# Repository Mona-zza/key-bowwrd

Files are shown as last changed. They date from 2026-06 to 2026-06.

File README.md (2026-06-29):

# ChapBoard

As my final exams are over and I've nothing to do untill first week of july so I utlized that time in upgrading my skill, I'm on my PC all the time and in thses time I've made this keyboard.

My this keyboard is equiped with 89 keys, 1 rotary encoder switch and 0.91" OLED display. In this I've used Raspberry Pi Pico 2W. I used this microcontroller because I guess it will be good because it has just enough GPIO pins for the key matrix + OLED and rotary encoder, and the 2W version of the Pico has wireless through the help of bluetooth if I decide to add that functionality in the future. For the case It has 2 separate printed pieces. The base, where the PCB sits, and the top cover, which protects the PCB. and I'll modify the CAD when I get more exact mesurments when the PCB will arrive!!

# Image











# Cart

cart1



## Bill of Materials (BOM)

| Item | Purpose | Qty | Total Price (USD) | Purchase Link | Distributor |
|---|---|----:|---:|---|---|
| PCB | PCB | 1 | $22.43 | N/A | JLCPCB |
| Raspberry Pi Pico 2W | Microcontroller | 1 | $14.82 | https://www.amazon.in/Raspberry-Dual-Core-Microcontroller-Cortex-M33-Bluetooth | Amazon |
| 0.91" OLED Display | Display | 1 | $4.11 | https://www.amazon.in/gp/product/B084H9HLCS | Amazon |
| 1N4148 Diodes | Diodes | 100 | $1.56 | https://www.amazon.in/gp/product/B0DRMGYSXB | Amazon |
| Rotary Encoder | Rotary Encoder | 1 | $1.82 | https://www.amazon.in/gp/product/B0888RWNM1 | Amazon |
| Cherry MX Switches | Switches | 89 | $5.28 | https://www.amazon.in/gp/product/B0G39H2G4H | Amazon |
| Keycaps | Keycaps | 89 | $10.56 | https://www.amazon.in/gp/product/B0GFNPXVJL | Amazon |
| Keycap Stabilizers Pack | Stabilizers | 1 | $9.18 | https://www.amazon.in/gp/product/B0GVKSLP46 | Amazon |
| Adafruit MCP23017 I²C GPIO Expander Breakout | GPIO Expander | 1 | $33.44 | https://www.amazon.in/gp/product/B0BPN3BD1Q | Amazon |
| M3×5×4 Heatset Inserts | Heatset Inserts | 1 | $2.07 | https://www.amazon.in/gp/product/B0CX1BS7DJ | Amazon |

### Total Cost

**≈ $105.27 USD**

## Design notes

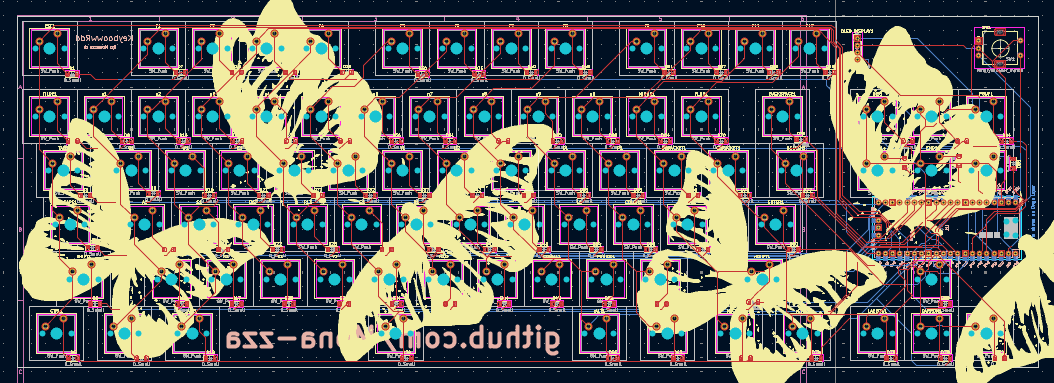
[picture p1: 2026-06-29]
Images/Screenshot2.png

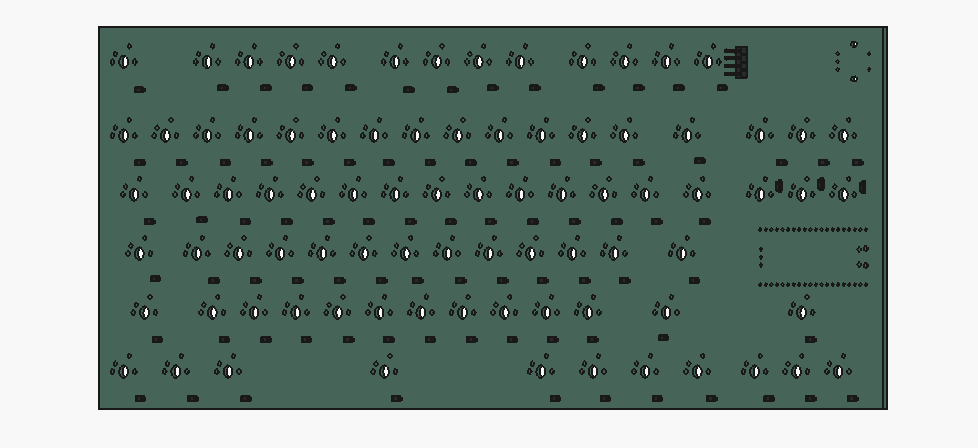
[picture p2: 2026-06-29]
Images/Screenshot7.png

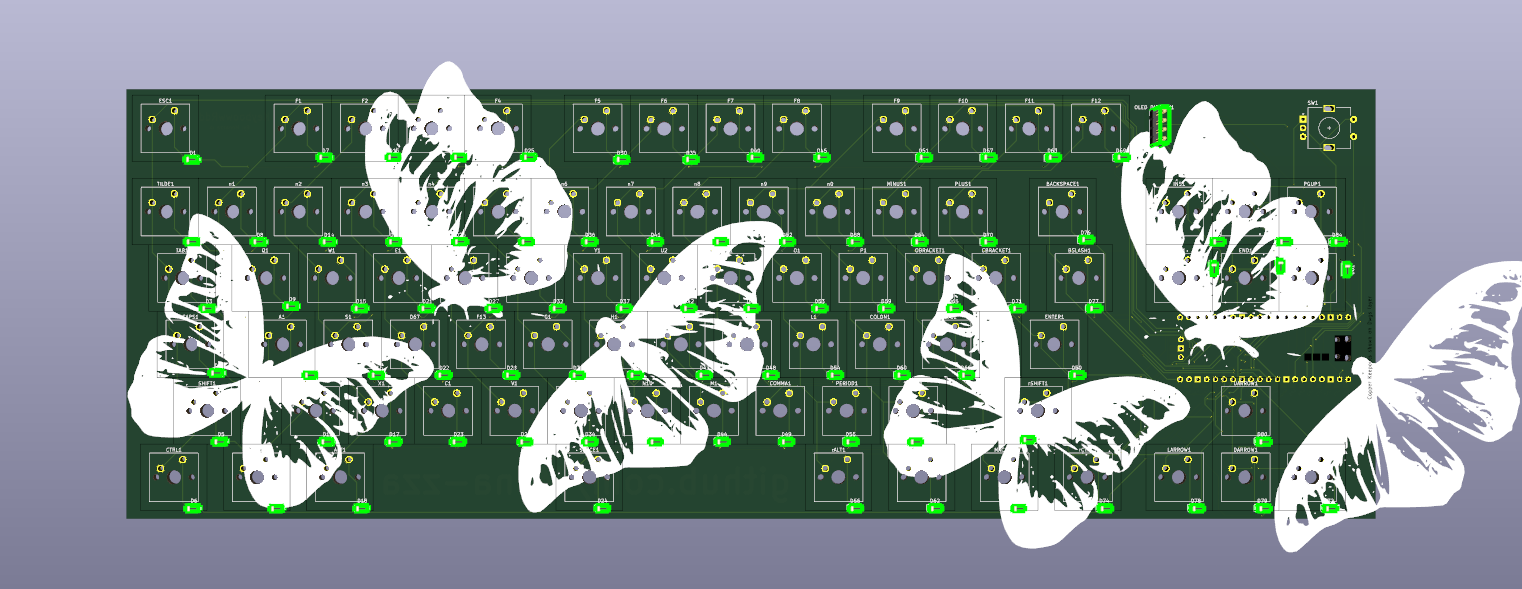
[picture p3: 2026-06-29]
Images/Screenshot3.png

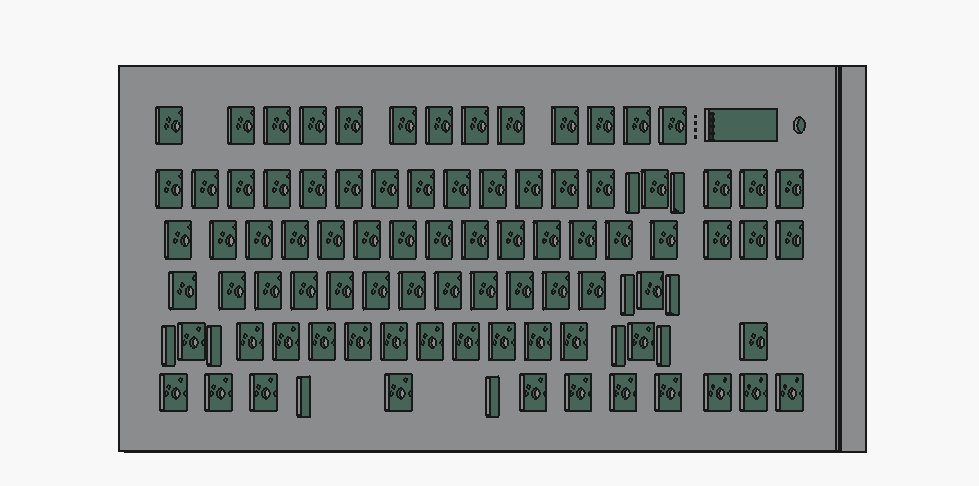
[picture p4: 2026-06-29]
Images/Screenshot6.png

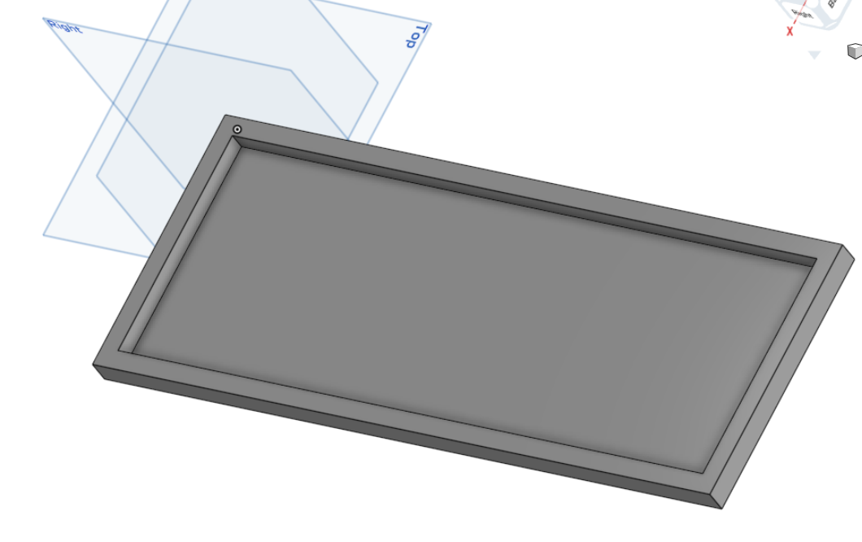
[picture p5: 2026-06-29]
Images/Screenshot4.png

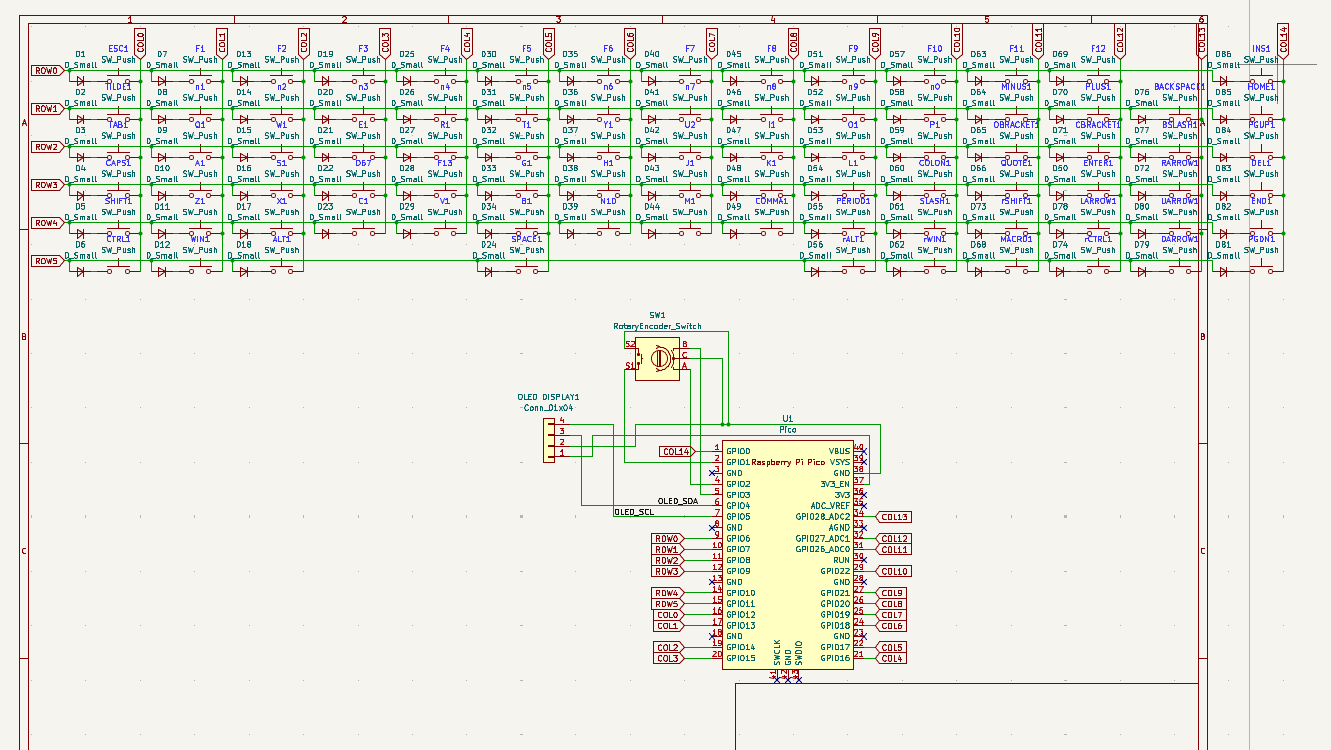
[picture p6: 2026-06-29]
Images/Screenshot1.png

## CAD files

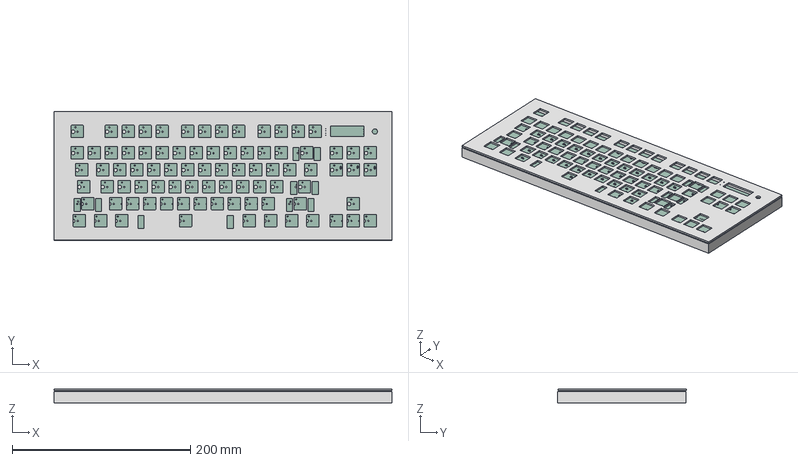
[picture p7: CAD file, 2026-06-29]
CAD/assembly.step
379.1 x 144.4 x 16.1 mm
D_SOD-123 x 84
PinHeader_1x04_P2.54mm_Vertical
keyboard_PCB

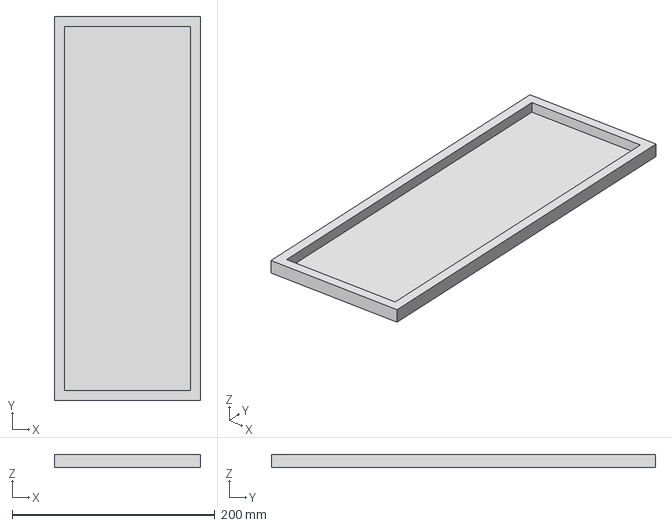
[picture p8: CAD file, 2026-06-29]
CAD/Keyboard-bottom.step
144.2 x 379.1 x 13.0 mm

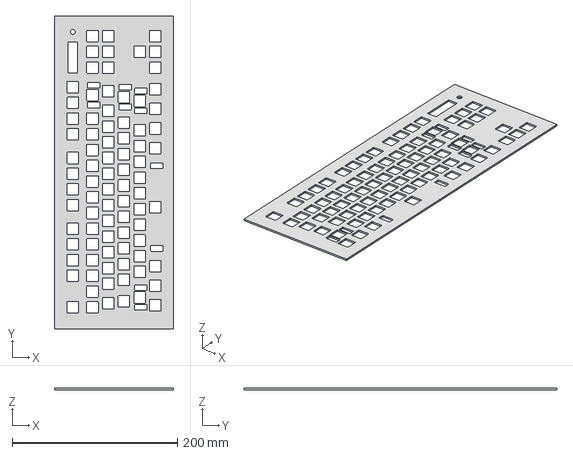
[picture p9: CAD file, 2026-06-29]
CAD/Keyboard-top.step
144.2 x 379.1 x 2.00 mm

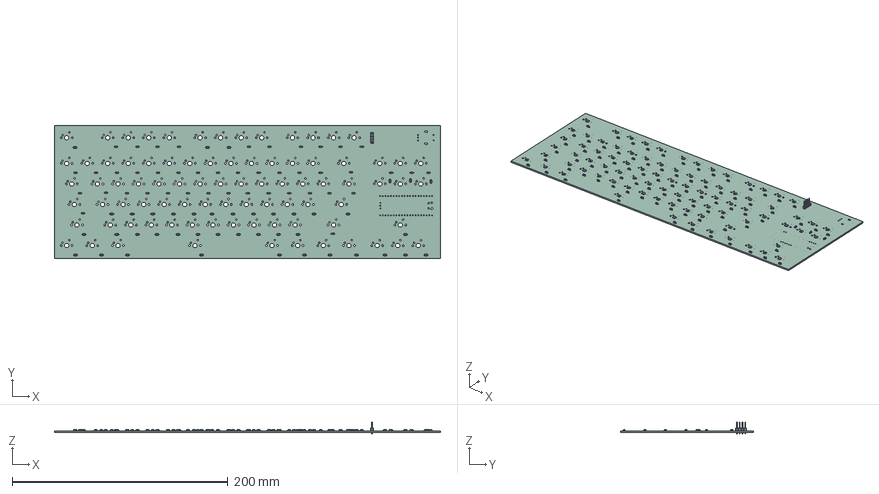
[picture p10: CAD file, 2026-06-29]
CAD/pcb.step
358.1 x 123.2 x 11.5 mm
D_SOD-123 x 84
PinHeader_1x04_P2.54mm_Vertical
keyboard_PCB

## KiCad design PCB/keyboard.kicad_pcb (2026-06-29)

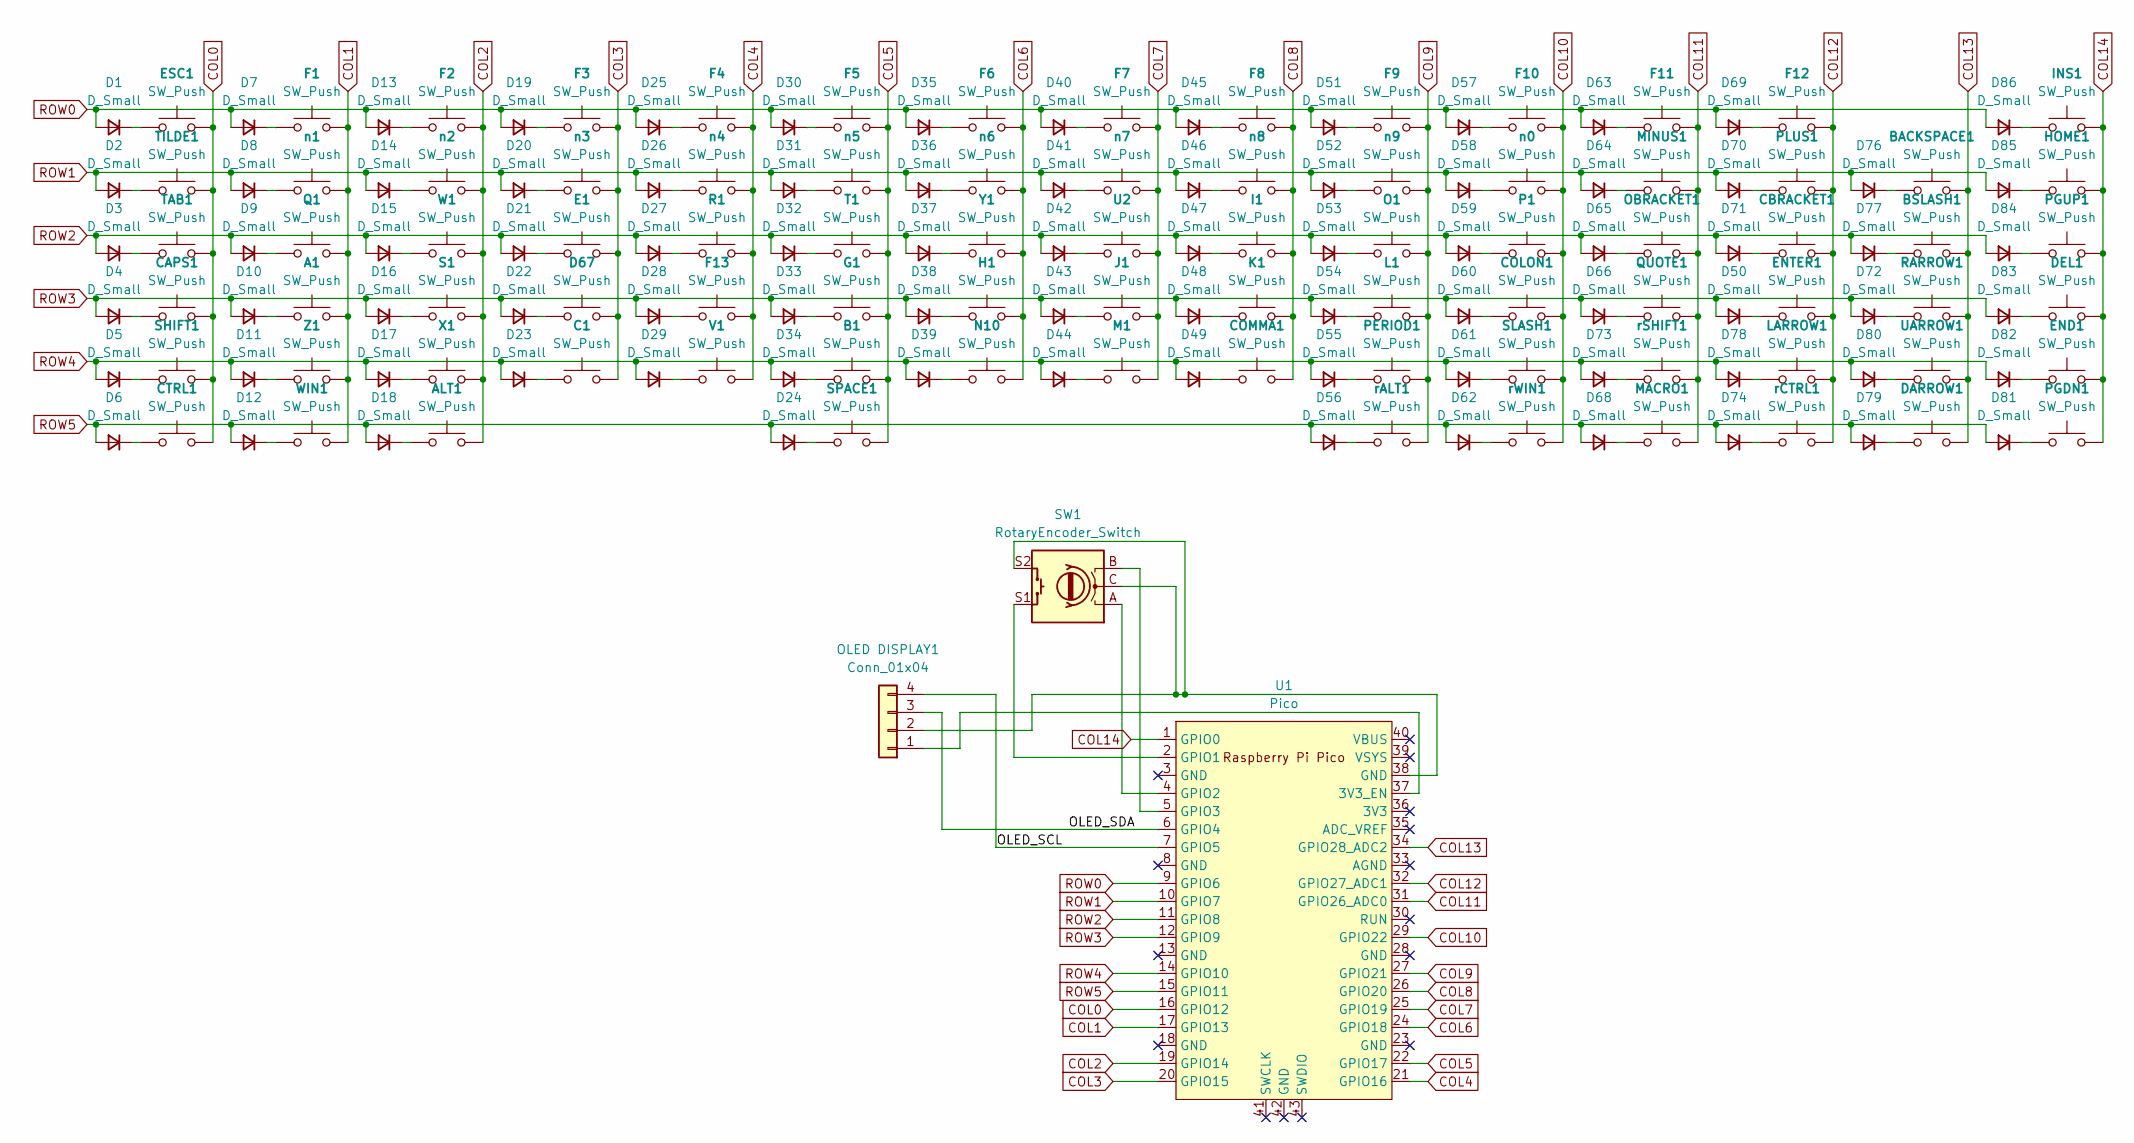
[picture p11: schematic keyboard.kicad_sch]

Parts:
A1: SW_Push; SW_Cherry_MX_1.00u_PCB
ALT1: SW_Push; SW_Cherry_MX_1.00u_PCB
B1: SW_Push; SW_Cherry_MX_1.00u_PCB
BACKSPACE1: SW_Push; SW_Cherry_MX_1.00u_PCB
BSLASH1: SW_Push; SW_Cherry_MX_1.00u_PCB
C1: SW_Push; SW_Cherry_MX_1.00u_PCB
CAPS1: SW_Push; SW_Cherry_MX_1.00u_PCB
CBRACKET1: SW_Push; SW_Cherry_MX_1.00u_PCB
COLON1: SW_Push; SW_Cherry_MX_1.00u_PCB
COMMA1: SW_Push; SW_Cherry_MX_1.00u_PCB
CTRL1: SW_Push; SW_Cherry_MX_1.00u_PCB
D1, D2, D3, D4, D5, D6, D7, D8, D9, D10, D11, D12, D13, D14, D15, D16, D17, D18, D19, D20, D21, D22, D23, D24, D25, D26, D27, D28, D29, D30, D31, D32, D33, D34, D35, D36, D37, D38, D39, D40, D41, D42, D43, D44, D45, D46, D47, D48, D49, D50, D51, D52, D53, D54, D55, D56, D57, D58, D59, D60, D61, D62, D63, D64, D65, D66, D68, D69, D70, D71, D72, D73, D74, D76, D77, D78, D79, D80, D81, D82, D83, D84, D85, D86: D_Small; D_SOD-123
D67: SW_Push; SW_Cherry_MX_1.00u_PCB
DARROW1: SW_Push; SW_Cherry_MX_1.00u_PCB
DEL1: SW_Push; SW_Cherry_MX_1.00u_PCB
E1: SW_Push; SW_Cherry_MX_1.00u_PCB
END1: SW_Push; SW_Cherry_MX_1.00u_PCB
ENTER1: SW_Push; SW_Cherry_MX_1.00u_PCB
ESC1: SW_Push; SW_Cherry_MX_1.00u_PCB
F1, F2, F3, F4, F5, F6, F7, F8, F9, F10, F11, F12, F13: SW_Push; SW_Cherry_MX_1.00u_PCB
G1: SW_Push; SW_Cherry_MX_1.00u_PCB
H1: SW_Push; SW_Cherry_MX_1.00u_PCB
HOME1: SW_Push; SW_Cherry_MX_1.00u_PCB
I1: SW_Push; SW_Cherry_MX_1.00u_PCB
INS1: SW_Push; SW_Cherry_MX_1.00u_PCB
J1: SW_Push; SW_Cherry_MX_1.00u_PCB
K1: SW_Push; SW_Cherry_MX_1.00u_PCB
L1: SW_Push; SW_Cherry_MX_1.00u_PCB
LARROW1: SW_Push; SW_Cherry_MX_1.00u_PCB
M1: SW_Push; SW_Cherry_MX_1.00u_PCB
MACRO1: SW_Push; SW_Cherry_MX_1.00u_PCB
MINUS1: SW_Push; SW_Cherry_MX_1.00u_PCB
N10: SW_Push; SW_Cherry_MX_1.00u_PCB
O1: SW_Push; SW_Cherry_MX_1.00u_PCB
OBRACKET1: SW_Push; SW_Cherry_MX_1.00u_PCB
OLED DISPLAY1: Conn_01x04; PinHeader_1x04_P2.54mm_Vertical
P1: SW_Push; SW_Cherry_MX_1.00u_PCB
PERIOD1: SW_Push; SW_Cherry_MX_1.00u_PCB
PGDN1: SW_Push; SW_Cherry_MX_1.00u_PCB
PGUP1: SW_Push; SW_Cherry_MX_1.00u_PCB
PLUS1: SW_Push; SW_Cherry_MX_1.00u_PCB
Q1: SW_Push; SW_Cherry_MX_1.00u_PCB
QUOTE1: SW_Push; SW_Cherry_MX_1.00u_PCB
R1: SW_Push; SW_Cherry_MX_1.00u_PCB
RARROW1: SW_Push; SW_Cherry_MX_1.00u_PCB
S1: SW_Push; SW_Cherry_MX_1.00u_PCB
SHIFT1: SW_Push; SW_Cherry_MX_1.00u_PCB
SLASH1: SW_Push; SW_Cherry_MX_1.00u_PCB
SPACE1: SW_Push; SW_Cherry_MX_1.00u_PCB
SW1: RotaryEncoder_Switch; RotaryEncoder_Alps_EC11E-Switch_Vertical_H20mm
T1: SW_Push; SW_Cherry_MX_1.00u_PCB
TAB1: SW_Push; SW_Cherry_MX_1.00u_PCB
TILDE1: SW_Push; SW_Cherry_MX_1.00u_PCB
U1: Pico; RPi_Pico_SMD_TH
U2: SW_Push; SW_Cherry_MX_1.00u_PCB
UARROW1: SW_Push; SW_Cherry_MX_1.00u_PCB
V1: SW_Push; SW_Cherry_MX_1.00u_PCB
W1: SW_Push; SW_Cherry_MX_1.00u_PCB
WIN1: SW_Push; SW_Cherry_MX_1.00u_PCB
X1: SW_Push; SW_Cherry_MX_1.00u_PCB
Y1: SW_Push; SW_Cherry_MX_1.00u_PCB
Z1: SW_Push; SW_Cherry_MX_1.00u_PCB
n0, n1, n2, n3, n4, n5, n6, n7, n8, n9: SW_Push; SW_Cherry_MX_1.00u_PCB
rALT1: SW_Push; SW_Cherry_MX_1.00u_PCB
rCTRL1: SW_Push; SW_Cherry_MX_1.00u_PCB
rSHIFT1: SW_Push; SW_Cherry_MX_1.00u_PCB
rWIN1: SW_Push; SW_Cherry_MX_1.00u_PCB

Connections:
/OLED_SCL: OLED DISPLAY1.4, U1.7 (GPIO5)
/OLED_SDA: OLED DISPLAY1.3, U1.6 (GPIO4)
COL0: CAPS1.2, CTRL1.2, ESC1.2, SHIFT1.2, TAB1.2, TILDE1.2, U1.16 (GPIO12)
COL1: A1.2, F1.2, Q1.2, U1.17 (GPIO13), WIN1.2, Z1.2, n1.2
COL2: ALT1.2, F2.2, S1.2, U1.19 (GPIO14), W1.2, X1.2, n2.2
COL3: C1.2, D67.2, E1.2, F3.2, U1.20 (GPIO15), n3.2
COL4: F4.2, F13.2, R1.2, U1.21 (GPIO16), V1.2, n4.2
COL5: B1.2, F5.2, G1.2, SPACE1.2, T1.2, U1.22 (GPIO17), n5.2
COL6: F6.2, H1.2, N10.2, U1.24 (GPIO18), Y1.2, n6.2
COL7: F7.2, J1.2, M1.2, U1.25 (GPIO19), U2.2, n7.2
COL8: COMMA1.2, F8.2, I1.2, K1.2, U1.26 (GPIO20), n8.2
COL9: F9.2, L1.2, O1.2, PERIOD1.2, U1.27 (GPIO21), n9.2, rALT1.2
COL10: COLON1.2, F10.2, P1.2, SLASH1.2, U1.29 (GPIO22), n0.2, rWIN1.2
COL11: F11.2, MACRO1.2, MINUS1.2, OBRACKET1.2, QUOTE1.2, U1.31 (GPIO26_ADC0), rSHIFT1.2
COL12: CBRACKET1.2, ENTER1.2, F12.2, LARROW1.2, PLUS1.2, U1.32 (GPIO27_ADC1), rCTRL1.2
COL13: BACKSPACE1.2, BSLASH1.2, DARROW1.2, RARROW1.2, U1.34 (GPIO28_ADC2), UARROW1.2
COL14: DEL1.2, END1.2, HOME1.2, INS1.2, PGDN1.2, PGUP1.2, U1.1 (GPIO0)
unnamed: D1.1 (K), ESC1.1
unnamed: D2.1 (K), TILDE1.1
unnamed: D3.1 (K), TAB1.1
unnamed: CAPS1.1, D4.1 (K)
unnamed: D5.1 (K), SHIFT1.1
unnamed: CTRL1.1, D6.1 (K)
unnamed: D7.1 (K), F1.1
unnamed: D8.1 (K), n1.1
unnamed: D9.1 (K), Q1.1
unnamed: A1.1, D10.1 (K)
unnamed: D11.1 (K), Z1.1
unnamed: D12.1 (K), WIN1.1
unnamed: D13.1 (K), F2.1
unnamed: D14.1 (K), n2.1
unnamed: D15.1 (K), W1.1
unnamed: D16.1 (K), S1.1
unnamed: D17.1 (K), X1.1
unnamed: ALT1.1, D18.1 (K)
unnamed: D19.1 (K), F3.1
unnamed: D20.1 (K), n3.1
unnamed: D21.1 (K), E1.1
unnamed: D22.1 (K), D67.1
unnamed: C1.1, D23.1 (K)
unnamed: D24.1 (K), SPACE1.1
unnamed: D25.1 (K), F4.1
unnamed: D26.1 (K), n4.1
unnamed: D27.1 (K), R1.1
unnamed: D28.1 (K), F13.1
unnamed: D29.1 (K), V1.1
unnamed: D30.1 (K), F5.1
unnamed: D31.1 (K), n5.1
unnamed: D32.1 (K), T1.1
unnamed: D33.1 (K), G1.1
unnamed: B1.1, D34.1 (K)
unnamed: D35.1 (K), F6.1
unnamed: D36.1 (K), n6.1
unnamed: D37.1 (K), Y1.1
unnamed: D38.1 (K), H1.1
unnamed: D39.1 (K), N10.1
unnamed: D40.1 (K), F7.1
unnamed: D41.1 (K), n7.1
unnamed: D42.1 (K), U2.1
unnamed: D43.1 (K), J1.1
unnamed: D44.1 (K), M1.1
unnamed: D45.1 (K), F8.1
unnamed: D46.1 (K), n8.1
unnamed: D47.1 (K), I1.1
unnamed: D48.1 (K), K1.1
unnamed: COMMA1.1, D49.1 (K)
unnamed: D50.1 (K), ENTER1.1
unnamed: D51.1 (K), F9.1
unnamed: D52.1 (K), n9.1
unnamed: D53.1 (K), O1.1
unnamed: D54.1 (K), L1.1
unnamed: D55.1 (K), PERIOD1.1
unnamed: D56.1 (K), rALT1.1
unnamed: D57.1 (K), F10.1
unnamed: D58.1 (K), n0.1
unnamed: D59.1 (K), P1.1
unnamed: COLON1.1, D60.1 (K)
unnamed: D61.1 (K), SLASH1.1
unnamed: D62.1 (K), rWIN1.1
unnamed: D63.1 (K), F11.1
unnamed: D64.1 (K), MINUS1.1
unnamed: D65.1 (K), OBRACKET1.1
unnamed: D66.1 (K), QUOTE1.1
unnamed: D68.1 (K), MACRO1.1
unnamed: D69.1 (K), F12.1
unnamed: D70.1 (K), PLUS1.1
unnamed: CBRACKET1.1, D71.1 (K)
unnamed: D72.1 (K), RARROW1.1
unnamed: D73.1 (K), rSHIFT1.1
unnamed: D74.1 (K), rCTRL1.1
unnamed: BACKSPACE1.1, D76.1 (K)
unnamed: BSLASH1.1, D77.1 (K)
unnamed: D78.1 (K), LARROW1.1
unnamed: D79.1 (K), DARROW1.1
unnamed: D80.1 (K), UARROW1.1
unnamed: D81.1 (K), PGDN1.1
unnamed: D82.1 (K), END1.1
unnamed: D83.1 (K), DEL1.1
unnamed: D84.1 (K), PGUP1.1
unnamed: D85.1 (K), HOME1.1
unnamed: D86.1 (K), INS1.1
unnamed: OLED DISPLAY1.1, U1.37 (3V3_EN)
unnamed: OLED DISPLAY1.2, SW1.C, SW1.S2, U1.38 (GND)
unnamed: SW1.S1, U1.2 (GPIO1)
unnamed: SW1.A, U1.4 (GPIO2)
unnamed: SW1.B, U1.5 (GPIO3)
ROW0: D1.2 (A), D7.2 (A), D13.2 (A), D19.2 (A), D25.2 (A), D30.2 (A), D35.2 (A), D40.2 (A), D45.2 (A), D51.2 (A), D57.2 (A), D63.2 (A), D69.2 (A), D86.2 (A), U1.9 (GPIO6)
ROW1: D2.2 (A), D8.2 (A), D14.2 (A), D20.2 (A), D26.2 (A), D31.2 (A), D36.2 (A), D41.2 (A), D46.2 (A), D52.2 (A), D58.2 (A), D64.2 (A), D70.2 (A), D76.2 (A), D85.2 (A), U1.10 (GPIO7)
ROW2: D3.2 (A), D9.2 (A), D15.2 (A), D21.2 (A), D27.2 (A), D32.2 (A), D37.2 (A), D42.2 (A), D47.2 (A), D53.2 (A), D59.2 (A), D65.2 (A), D71.2 (A), D77.2 (A), D84.2 (A), U1.11 (GPIO8)
ROW3: D4.2 (A), D10.2 (A), D16.2 (A), D22.2 (A), D28.2 (A), D33.2 (A), D38.2 (A), D43.2 (A), D48.2 (A), D50.2 (A), D54.2 (A), D60.2 (A), D66.2 (A), D72.2 (A), D83.2 (A), U1.12 (GPIO9)
ROW4: D5.2 (A), D11.2 (A), D17.2 (A), D23.2 (A), D29.2 (A), D34.2 (A), D39.2 (A), D44.2 (A), D49.2 (A), D55.2 (A), D61.2 (A), D73.2 (A), D78.2 (A), D80.2 (A), D82.2 (A), U1.14 (GPIO10)
ROW5: D6.2 (A), D12.2 (A), D18.2 (A), D24.2 (A), D56.2 (A), D62.2 (A), D68.2 (A), D74.2 (A), D79.2 (A), D81.2 (A), U1.15 (GPIO11)

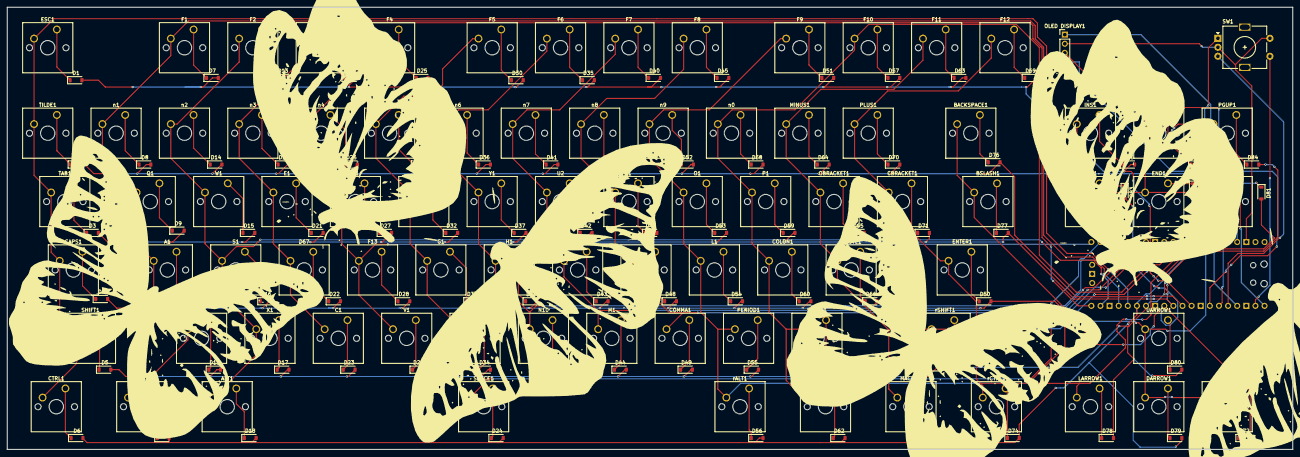
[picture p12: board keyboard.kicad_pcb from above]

Board: 2 copper layers, 358.1 x 123.2 mm, 171 parts (1 on the bottom side), 112 nets.

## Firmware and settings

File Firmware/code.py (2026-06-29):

from kmk.kmk_keyboard import KMKKeyboard
from kmk.keys import KC
from kmk.scanners import DiodeOrientation
import board

keyboard = KMKKeyboard()

# Rows: ROW0..ROW5
keyboard.row_pins = (
    board.GP6,
    board.GP7,
    board.GP8,
    board.GP9,
    board.GP10,
    board.GP11,
)

# Cols: COL0..COL14
keyboard.col_pins = (
    board.GP12,  # COL0
    board.GP13,  # COL1
    board.GP14,  # COL2
    board.GP15,  # COL3
    board.GP16,  # COL4
    board.GP17,  # COL5
    board.GP18,  # COL6
    board.GP19,  # COL7
    board.GP20,  # COL8
    board.GP21,  # COL9
    board.GP22,  # COL10
    board.GP26,  # COL11
    board.GP27,  # COL12
    board.GP28,  # COL13
    board.GP0,   # COL14
)

keyboard.diode_orientation = DiodeOrientation.ROW2COL

keyboard.keymap = [[
    # Row 0 (15)
    KC.ESC, KC.TAB, KC.BSPC, KC.LSFT, KC.LCTL, KC.LALT, KC.LGUI, KC.RGUI, KC.RALT, KC.RCTL, KC.RSFT, KC.NO, KC.NO, KC.NO, KC.NO,
    # Row 1 (15)
    KC.F1, KC.F2, KC.F3, KC.F4, KC.F5, KC.F6, KC.F7, KC.F8, KC.F9, KC.F10, KC.F11, KC.F12, KC.NO, KC.NO, KC.NO,
    # Row 2 (15)
    KC.N1, KC.N2, KC.N3, KC.N4, KC.N5, KC.N6, KC.N7, KC.N8, KC.N9, KC.N0, KC.NO, KC.NO, KC.NO, KC.NO, KC.NO,
    # Row 3 (15)
    KC.Q, KC.W, KC.E, KC.R, KC.T, KC.Y, KC.U, KC.I, KC.O, KC.P, KC.LBRC, KC.RBRC, KC.BSLS, KC.MINS, KC.EQL,
    # Row 4 (15)
    KC.A, KC.S, KC.D, KC.F, KC.G, KC.H, KC.J, KC.K, KC.L, KC.SCLN, KC.QUOT, KC.ENT, KC.NO, KC.NO, KC.NO,
    # Row 5 (15)
    KC.Z, KC.X, KC.C, KC.V, KC.B, KC.N, KC.M, KC.COMM, KC.DOT, KC.SLSH, KC.SPC, KC.NO, KC.NO, KC.NO, KC.NO,


]]

if __name__ == "__main__":
    keyboard.go()
